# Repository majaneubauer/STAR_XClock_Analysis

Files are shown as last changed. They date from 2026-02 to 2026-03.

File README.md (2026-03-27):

# Protocol for an open-source system to synchronize neural and behavioral data acquisition using the custom Python package XClock and a LabJack T4

The specially developed, open-source Python package XClock developed by interfaces with a LabJack T4 microcontroller and allows researchers to 

# Commercially available and custom-made parts

The following component list details the quantity, supplier, and part number of each item required to fabricate and assemble the three-chamber sociability arena.

| Quantity | Part Name | Supplier | Part Number | Unit Price | Total Price |
|---|---|---|---|---|---|
| 1 | PLEXIGLAS® Satinice sheet 700 x 450 (6 mm thickness)  | [ACRYLICS](https://acrylglas-shop.com/)  | [60940](https://acrylglas-shop.com/plexiglas-gs-satinice-wh10-dc-weiss-snow-staerke-6-mm)  | 42.21 €  | 42.21 €  |
| 2 | PLEXIGLAS® Satinice sheet 750 x 450 (6 mm thickness)  | [ACRYLICS](https://acrylglas-shop.com/)  | [60940](https://acrylglas-shop.com/plexiglas-gs-satinice-wh10-dc-weiss-snow-staerke-6-mm)  | 45.22 €  | 90.44 €  |
| 1 | PLEXIGLAS® Satinice sheet 650 x 250 (6 mm thickness)  | [ACRYLICS](https://acrylglas-shop.com/)  | [60940](https://acrylglas-shop.com/plexiglas-gs-satinice-wh10-dc-weiss-snow-staerke-6-mm) | 21.77 € | 21.77 € |
| 1 | PLEXIGLAS® Satinice sheet 400 x 300 (8 mm thickness) | [ACRYLICS](https://acrylglas-shop.com/) | [60950](https://acrylglas-shop.com/plexiglas-gs-satinice-wh10-dc-weiss-snow-staerke-8-mm) | 19.30 €  | 19.30€  |
| 1 | PLEXIGLAS® Clear sheet 650 x 250 (3 mm thickness)  | [ACRYLICS](https://acrylglas-shop.com/)  | [60300](https://acrylglas-shop.com/plexiglas-xt-staerke-3-mm-farblos)  | 6.44 €  | 6.44 €  |
| 8 | Aluminum profile (Nut 6) 20 x 20 x 200 mm  | [Aluprofile 24](https://aluprofile24.de/)  | [P20N6](https://aluprofile24.de/product_info.php?info=p2_strebenprofil-20x20-nut-6---zuschnitt.html)  | 0.62 €  | 4.98 €  |
| 32  | Slot nut (Nut 6, Thread M6)  | [Aluprofile 24](https://aluprofile24.de/)  | [NUSTSN6B](https://aluprofile24.de/product_info.php?info=p15_nutenstein-nut-6.html)  | 0.18 €  |  5.76 € |
| 2 (Pack of 25)  | M6 x 1.0 Stainless Steel Cap Screw, (32 screws needed for assembly) | [Thorlabs](https://www.thorlabs.com/)  | [SH6MS10](https://www.thorlabs.com/item/SH6MS10)  | 8.84 €  | 17.68 €  |
| 1 (Pack of 100)  | 1/4" Washer, M6 Compatible, Stainless Steel, (32 washers needed for assembly)  | [Thorlabs](https://www.thorlabs.com/)  | [W25S050](https://www.thorlabs.com/item/W25S050)  | 5.29 €  | 5.29 €  |

# Fabrication of the custom parts for the three-chamber sociability arena

This is a list of components that need to be fabricated (laser-cut) from the 6 mm thick PLEXIGLAS® Satinice sheets:
- long outer wall (2x)
- short outer wall (2x)
- chamber separation wall (4x)
- outer part of the door (2 per door, 4x in total)
- separation reinforcement wall (2x)

This is a list of components that need to be fabricated (laser-cut) from the 8 mm thick PLEXIGLAS® Satinice sheet:
- inner part of the door (1 per door, 2x in total)

This is a list of components that need to be fabricated (laser-cut) from the 3 mm thick PLEXIGLAS® Clear sheet:
- corner compartment walls (4x)
- corner compartment holders (8x; byproduct of the open interaction slots in the corner compartment walls)

Figure_1_Fabricate_the_custom_parts

**Figure 1.** Laser-cut parts of the three-chamber sociability arena  
(A) NE isometric view of the assembled three-chamber sociability arena, labeled to include the (1) two long outer walls, (2) two short outer walls, (3) four chamber separation walls, (4) two separation reinforcement walls, (5) four corner compartment walls, and (6) eight corner compartment holders. The second door is omitted for visual clarity.  
(B) Aerial view of the configuration shown in (A), labeled to include one door, consisting of (1a) two outer parts, and (1b) one inner part.

## Arranging of the sketches

We use an [OMTech laser cutter](https://de.omtech.com/products/100w-co2-laser-graviermaschine-cutter-mit-100x-60cm-bearbeitungsflache-autofokus-max-gr10) with a working range of 1000 x 600 mm. The size of the PLEXIGLAS® sheets listed above ([Commercially available and custom-made parts](#commercially-available-and-custom-made-parts)) has been calculated to fit as many components on one sheet as possible while still maintaining a minimum clearance of 1 cm from all edges and adjacent components. See the images below on how we arranged the sketches (DXF files) in RDWorks.

Both long outer walls (700 x 450 x 6 mm PLEXIGLAS® Satinice sheet):  
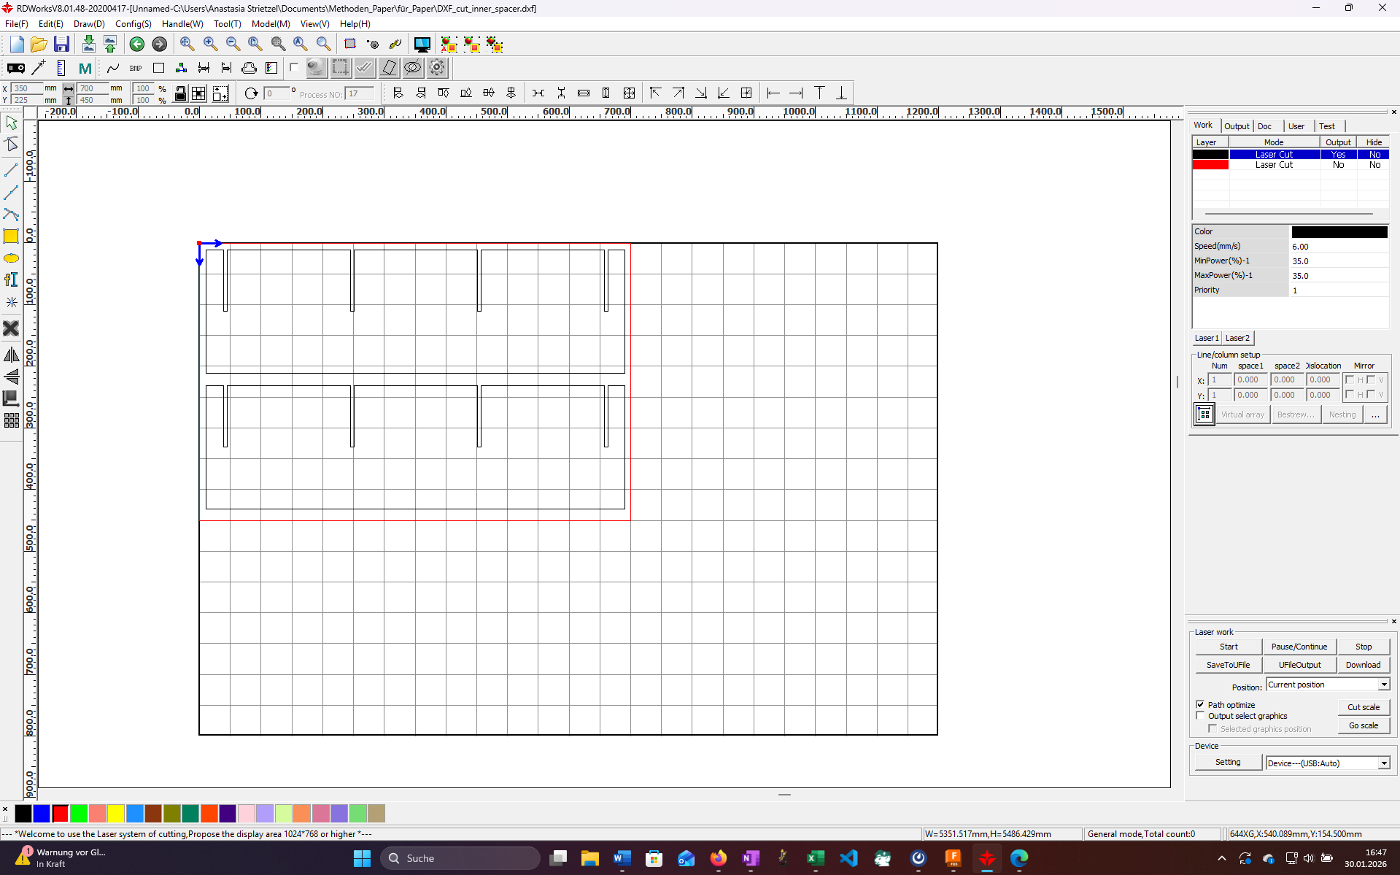
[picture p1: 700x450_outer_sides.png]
long_outer_walls


Both short outer walls and two of four chamber separation walls (750 x 450 x 6 mm PLEXIGLAS® Satinice sheet):  
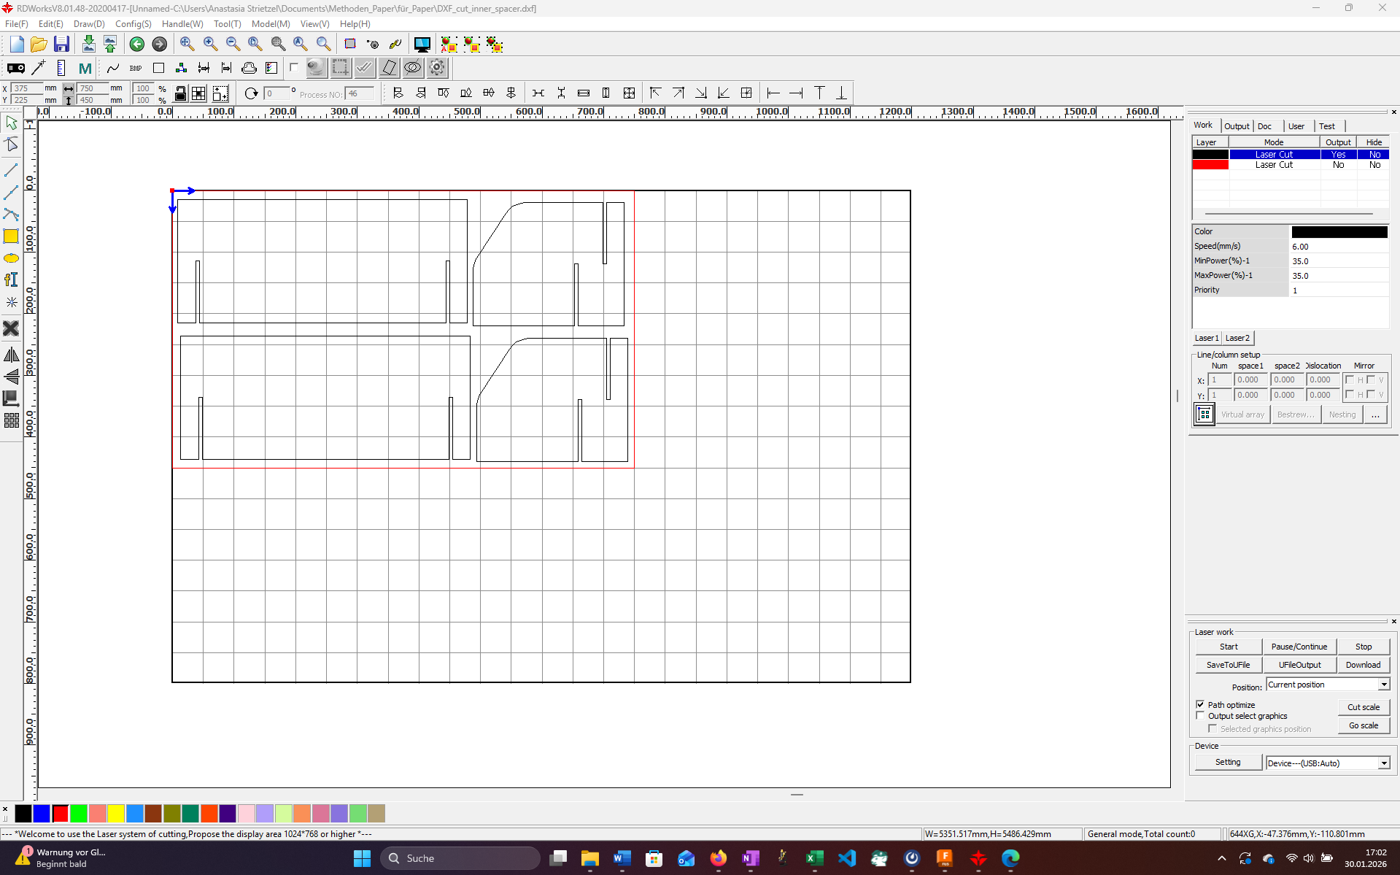
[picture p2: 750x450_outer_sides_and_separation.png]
short_outer_walls_chamber_separation


Remaining two chamber separation walls and all four outer parts of the doors (750 x 450 x 6 mm PLEXIGLAS® Satinice sheet):  
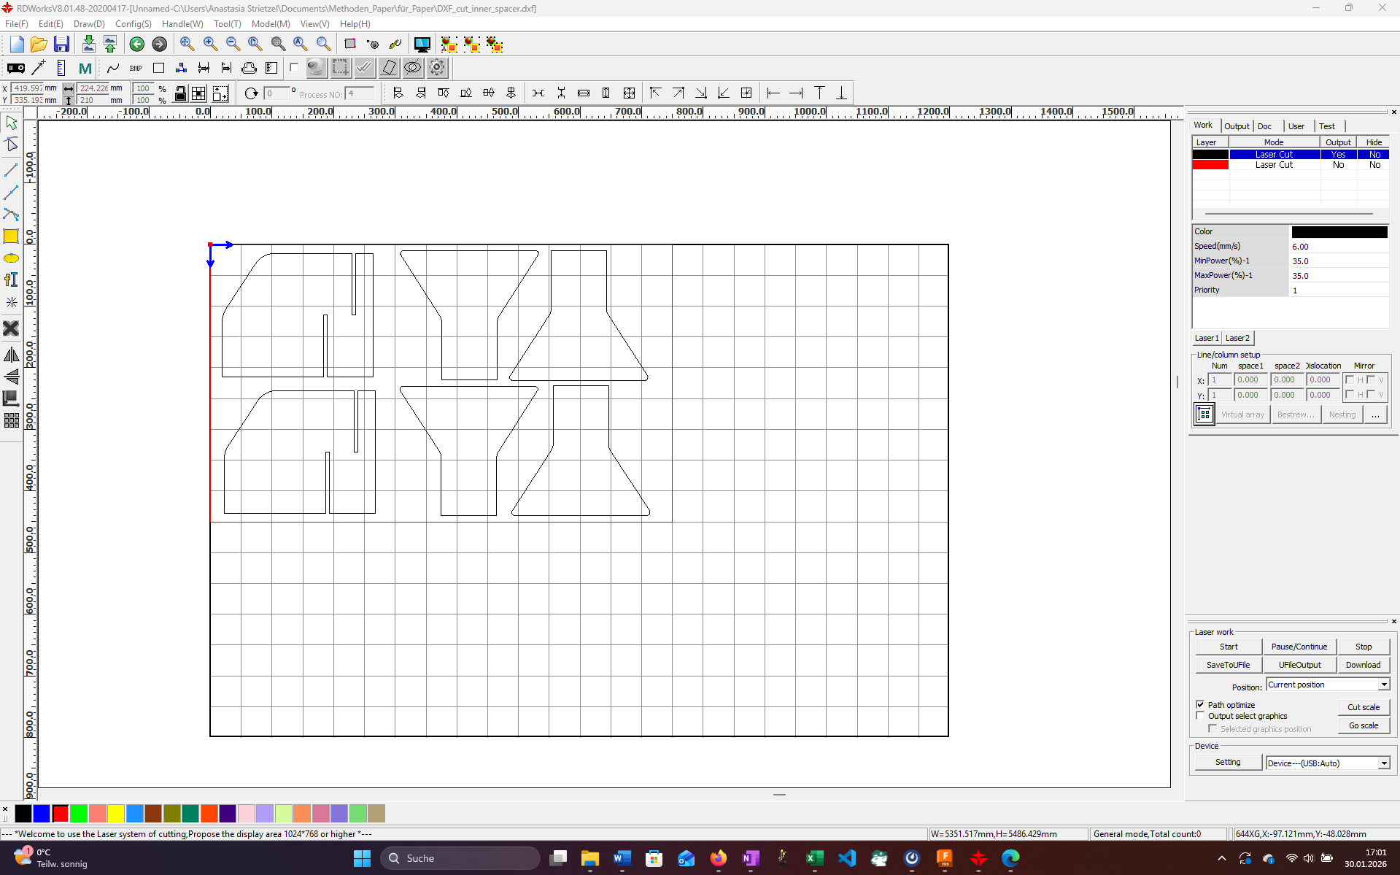
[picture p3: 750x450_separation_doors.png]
chamber_separation_outer_doors


Both separtion reinforcement walls (600 x 250 x 6 mm PLEXIGLAS® Satinice sheet):  
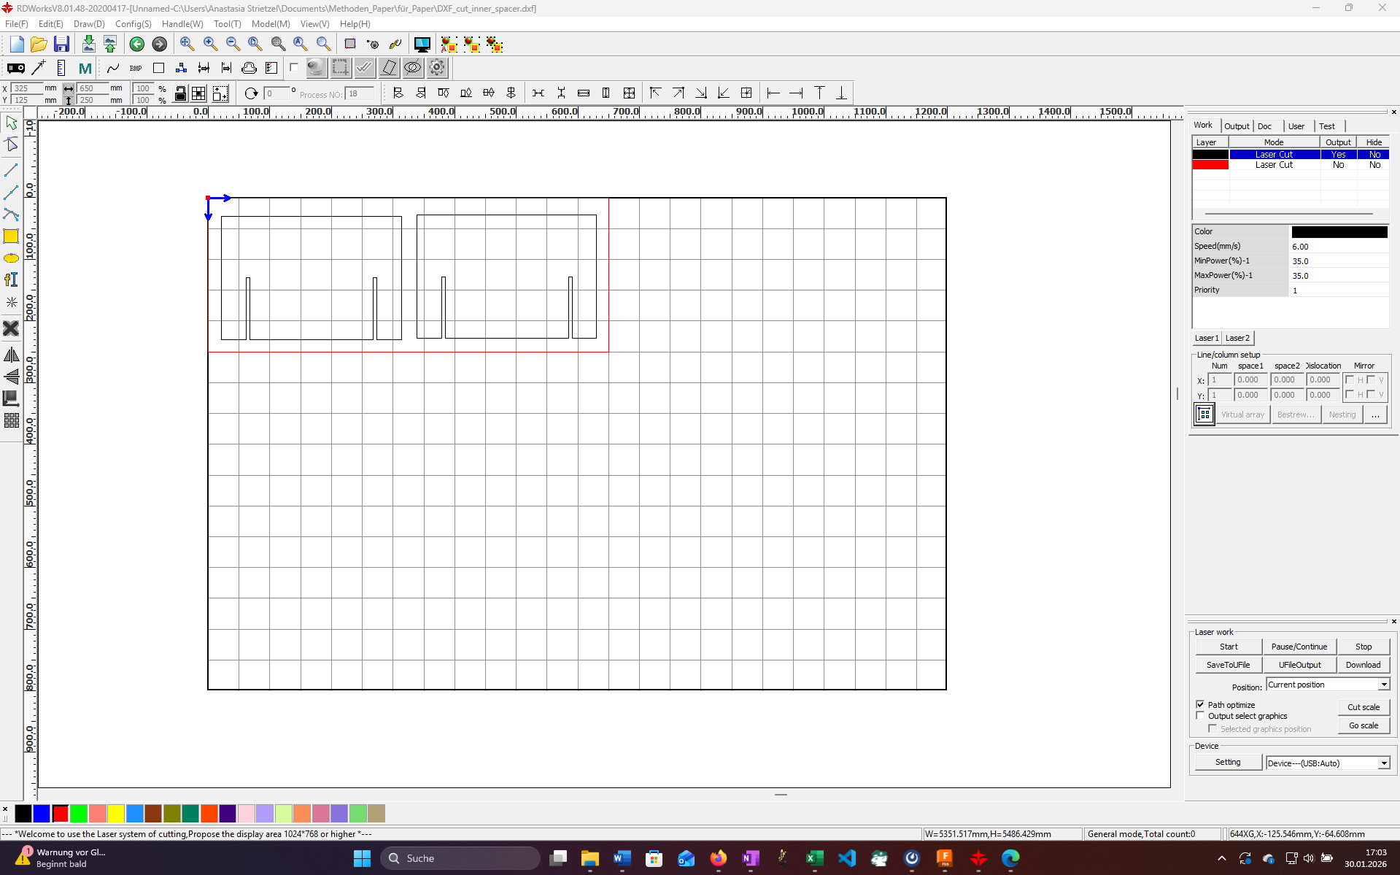
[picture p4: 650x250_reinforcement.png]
reinforcement_walls


Both inner parts of the doors (400 x 300 x 8 mm PLEXIGLAS® Satinice sheet):
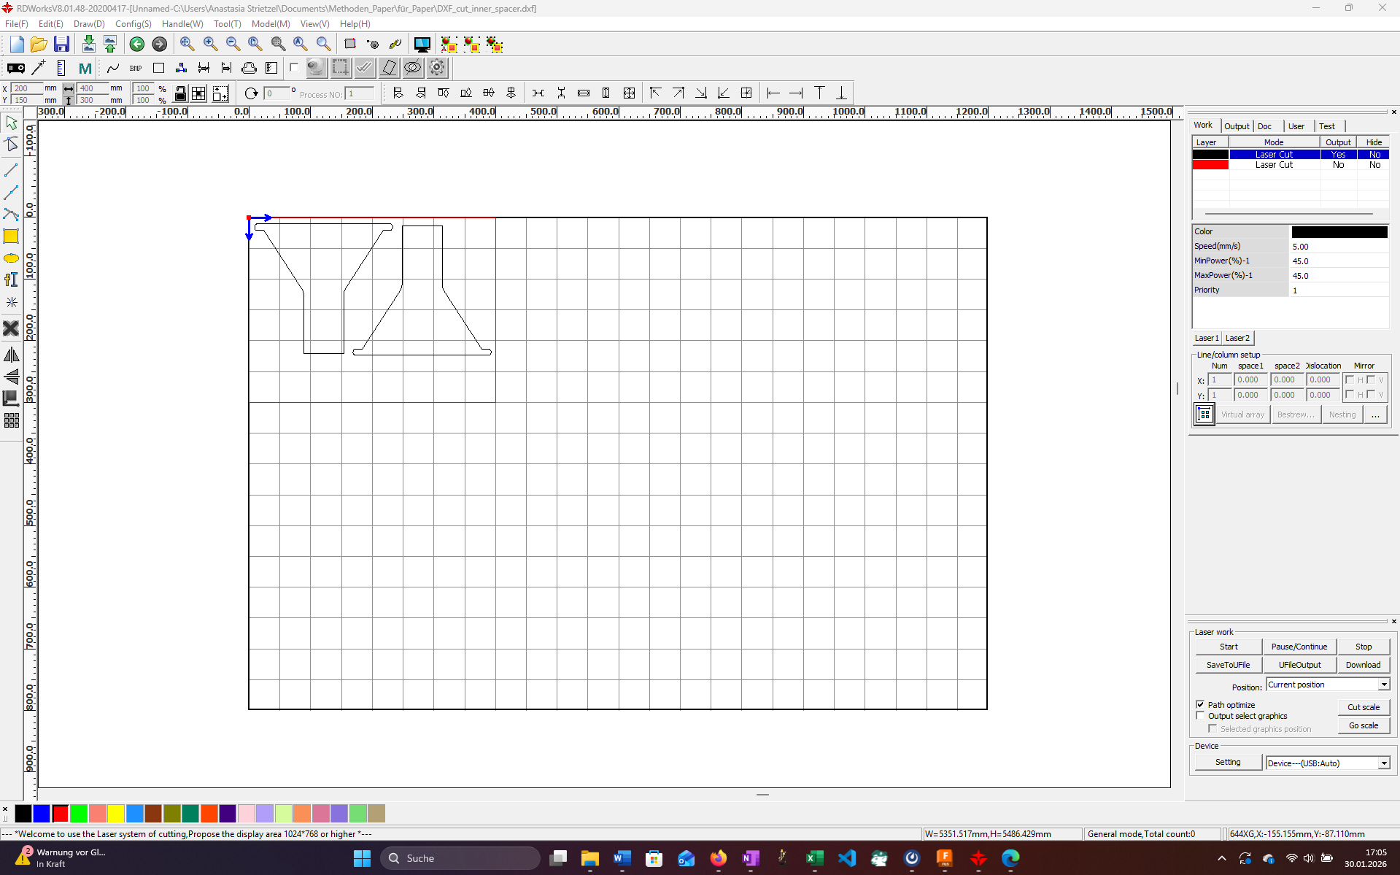
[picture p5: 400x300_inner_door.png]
inner_doors


All four corner compartment walls (650 x 250 x 3 mm PLEXIGLAS® Clear sheet); yields the needed eight corner compartment holders:
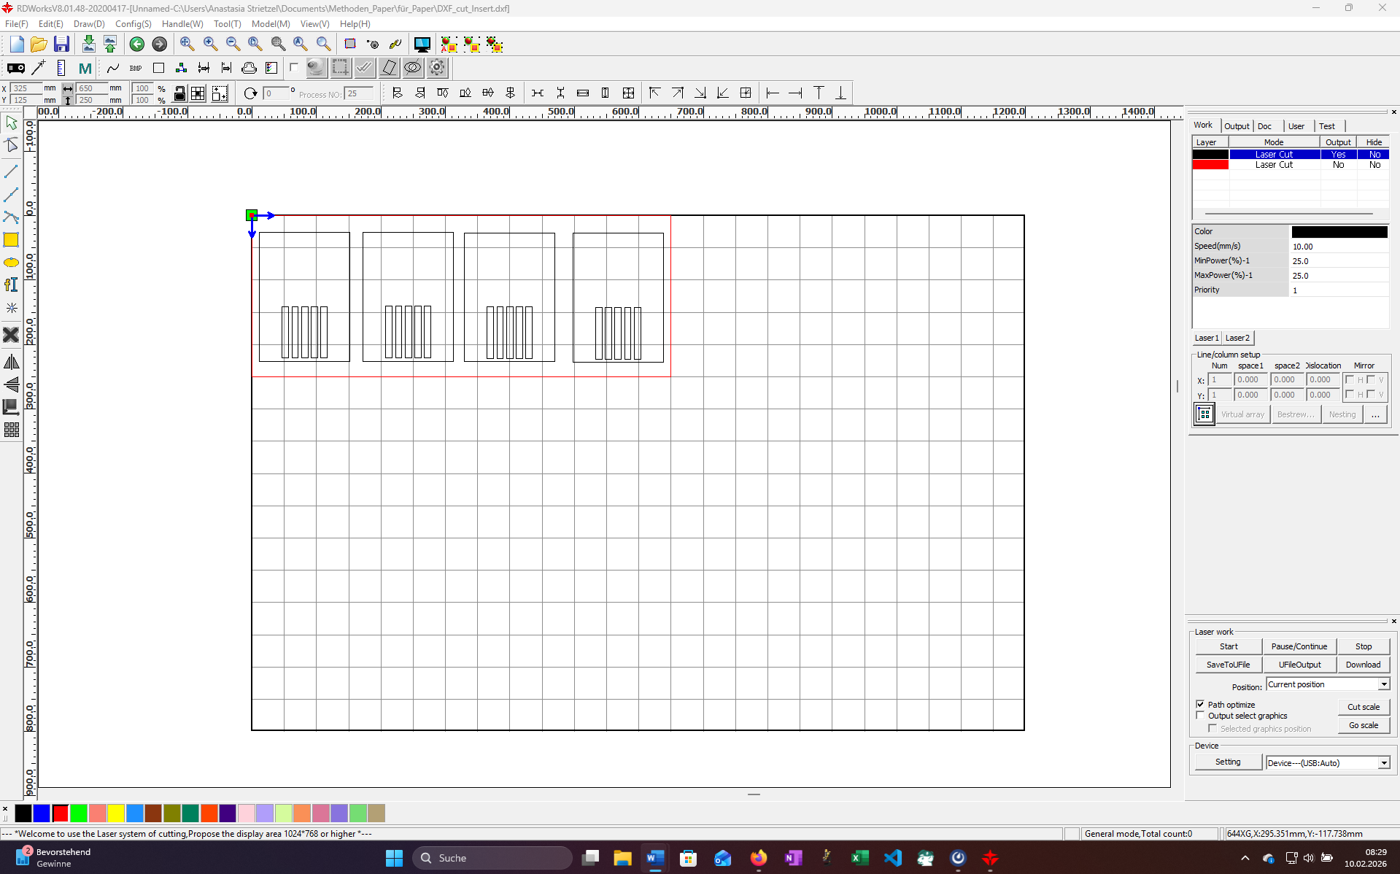
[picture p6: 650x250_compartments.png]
corner_compartment_walls


# Assembly of the three-chamber sociability arena

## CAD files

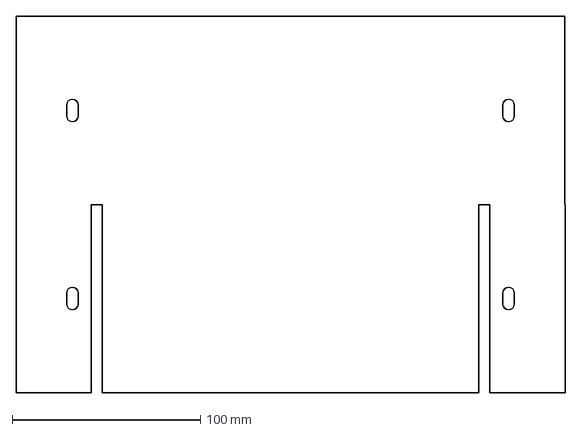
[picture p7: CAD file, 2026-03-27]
Digital_Design_Files/DXF_cut_separation_reinforcement_wall.dxf
292.0 x 200.0 mm

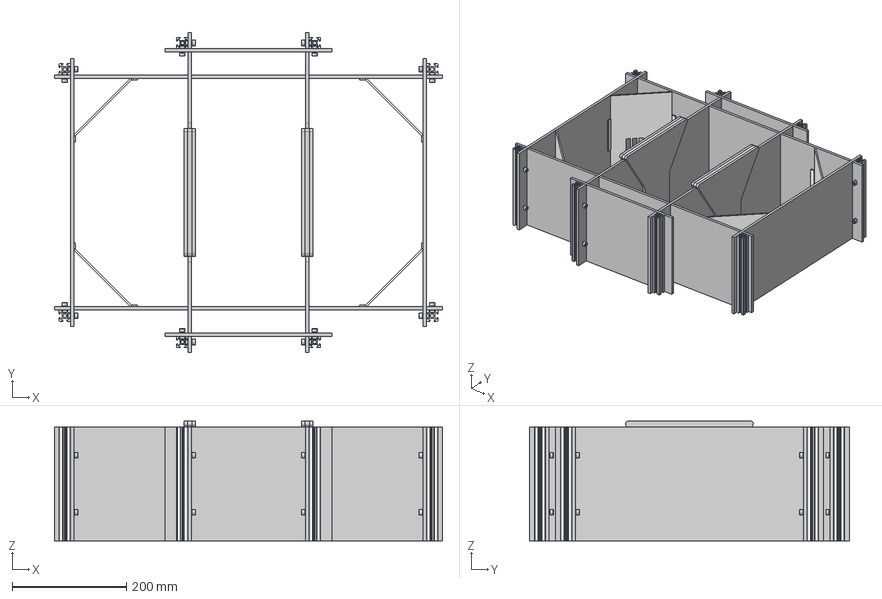
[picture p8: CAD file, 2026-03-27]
Digital_Design_Files/Three-Chamber_Sociability_Arena.step
680.0 x 560.0 x 210.0 mm
Einsatz x 4
U x 2
Insert x 4
Insert_Holder x 8
DIN 912 - M6 x 1 x 10 Stahl 4.6 Einfach x 31
20X20 200 0/0-MB x 8
M6_nut x 32
lange Seite neu x 2
kurze Seite neu x 2
DIN 912 - M6 x 1 x 10 Edelstahl A2 Einfach x 2
door_1_outer_part x 2
door_1_inner_part
door_2_inner_part
door_2_outer_part x 2

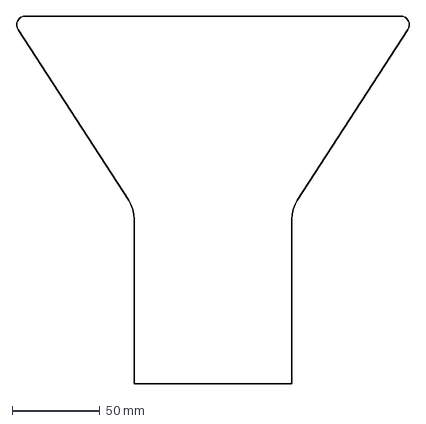
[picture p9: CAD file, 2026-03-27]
Digital_Design_Files/DXF_cut_outer_door.dxf
224.8 x 210.0 mm

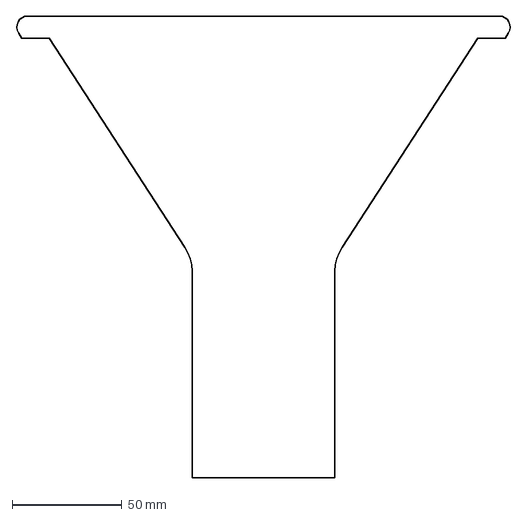
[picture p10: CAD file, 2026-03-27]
Digital_Design_Files/DXF_cut_inner_door.dxf
224.8 x 210.0 mm

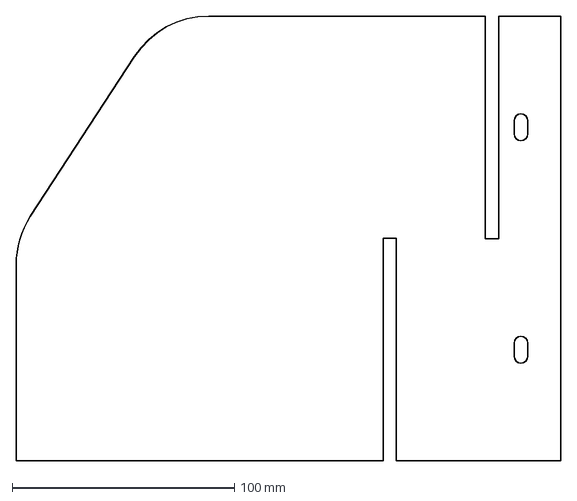
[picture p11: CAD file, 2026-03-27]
Digital_Design_Files/DXF_cut_chamber_separation_wall.dxf
245.0 x 200.0 mm

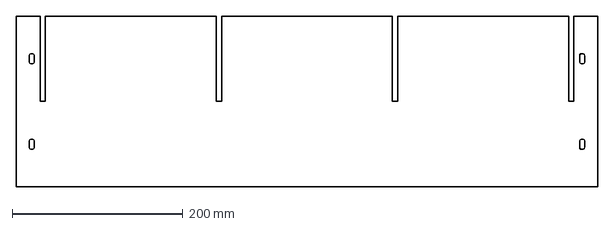
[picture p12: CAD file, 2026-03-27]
Digital_Design_Files/DXF_cut_long_outer_wall.dxf
680.0 x 200.0 mm

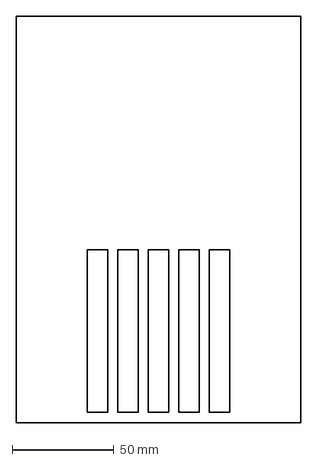
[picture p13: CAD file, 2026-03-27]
Digital_Design_Files/DXF_cut_corner_compartment_wall.dxf
140.0 x 200.0 mm

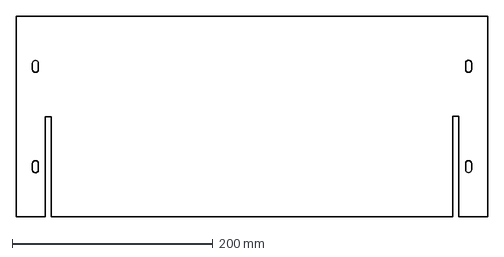
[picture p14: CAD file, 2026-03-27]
Digital_Design_Files/DXF_cut_short_outer_wall.dxf
470.0 x 200.0 mm

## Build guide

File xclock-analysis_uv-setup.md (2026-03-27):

# uv setup for Python analysis projects (using IDEs like PyCharm or VS Code)

## Create a new project folder
for Windows (PowerShell or CMD)
```
mkdir x-clock-analysis
cd x-clock-analysis
```
macOS/Linux
```
mkdir -p x-clock-analysis
cd x-clock-analysis
```

## Initialize a uv project
Creates ```pyproject.toml``` for dependency management.
```
uv init
```

## Create / sync the virtual environment
Resolves dependencies and creates (or updates) a local virtual environment (typically ```.venv/```).
```
uv sync
```

## Create the virtual environment and adds core scientific packages
Adds dependencies to ```pyproject.toml``` and installs them into the environment.
```
uv add h5py ipykernel matplotlib numpy opencv-python pandas scipy
```

## IDE setup (e.g., PyCharm)

1. Open the folder ```x-clock-analysis``` in PyCharm.

2. Set the interpreter to the uv venv:

   - Settings/Preferences → Project → Python Interpreter
   - Add Interpreter → Existing
   - Select:
     - Windows: ```x-clock-analysis\.venv\Scripts\python.exe```
     - macOS/Linux: ```x-clock-analysis/.venv/bin/python```

## Run code in the uv environment without activating venv manually (terminal friendly)
Use ```uv run``` to execute Python/scripts with the project environment.
```
uv run python -c "import numpy, pandas, matplotlib; print('ok')"
uv run python your_script.py
```

## Maintain the environment
Add packages later:
```
uv add <package>
```
Remove packages:
```
uv remove <package>
```
Re-resolve / sync after changes:
```
uv sync
```
